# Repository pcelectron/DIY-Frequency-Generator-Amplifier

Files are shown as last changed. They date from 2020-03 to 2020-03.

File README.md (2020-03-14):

# DIY-Frequency-Generator-Amplifier

This is a open source frequency generator amplifier capable of delivering up to 1.5 Amps and 28 Vpp at up to 100MHz. It is based on three THS3491 IC's in parallel. The gain of the amplifier stage is fixed at 2, but can be changed by changing the feedback network resistors.
This Repo has the Kicad project files, gerbers, BOM and 3d models of the board and case. Please make a pull request if you have imporvements, which you find to be useful for others.

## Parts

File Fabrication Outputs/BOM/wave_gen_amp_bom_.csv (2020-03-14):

Component | References | Value | Footprint | Quantity Per PCB | digikey order number
1 | C7 C8 C9 C10 C11 C12 C28 | 100n | C_0603_1608Metric | 7 | C0603C104M5RACTU
2 | C13 C14 C15 C16 C17 C18 | 100p | C_0402_1005Metric | 6 | CC0402JRNPO9BN101
3 | C19 | 10n | C_0402_1005Metric | 1 | 311-1349-1-ND
4 | C1 C2 C3 C4 C5 C6 C20 C21 C22 C23 C24 C25 C26 C27 | 10u | C_1210_3225Metric | 14 | 1276-3387-1-ND
5 | D1 | D | S1M-13-F | 1 | S1M-13-F
6 | J1 | Banana Blue | banana_female_panel_mount | 1 | 108-0910-001
7 | J2 | Banana Black | banana_female_panel_mount | 1 | 108-0903-001
8 | J3 | Banana Red | banana_female_panel_mount | 1 | 108-0902-001
9 | J4 J5 | Conn_Coaxial | VBITE_BNC | 2 | 031-6233
10 | J7 | FAN | Conn_2x1_smd_horizontal | 1 | TSM-102-01-T-SH
11 | Q1 | DMG2302U | SOT-23 | 1 | DMG2302UK-7
12 | R11 | 12.4k | R_0603_1608Metric | 1 | RNCP0603FTD12K4CT-ND
13 | R10 | 140k | R_0603_1608Metric | 1 | RMCF0603FT140KCT-ND
14 | R13 R14 R17 R19 | 1k | R_0603_1608Metric | 4 | 311-1.00KHRCT-ND
15 | R7 R8 R9 | 2.4R | R_2010_5025Metric | 3 | 35022R4FT
16 | R18 | 3.2k | R_0603_1608Metric | 1 | 2019-RN73H1JTTD3201F100CT-ND
17 | R15 R16 | 30k | R_0603_1608Metric | 2 | 311-30.0KHRCT-ND
18 | R12 | 50R | R_0603_1608Metric | 1 | 541-2655-1-ND
19 | R1 R2 R3 R4 R5 R6 | 976R | R_0402_1005Metric | 6 | RP73PF1E976RBTD
20 | RV2 | COMP_REF | Trimpot_3.8mmx3.6mm_TC33X-2-103E | 1 | TC33X-2-103E
21 | RV1 | TJ_REF | Trimpot_3.8mmx3.6mm_TC33X-2-103E | 1 | TC33X-2-103E
22 | SH1 | RF_Shield_One_Piece | SHIELD | 1
23 | U6 | CU_SKV606021 | CU_SKV606021 | 1 | SKV606021-CU
24 | U4 | L7815 | TO-263-3 | 1 | L7815CD2T-TR
25 | U8 | LM2940 | SOT-223 | 1 | LM2940IMP-12/NOPBCT-ND
26 | U5 | LT3015 | DFN-8-1EP_3x3mm_P0.65mm_EP1.55x2.4mm | 1 | LT3015EDD#PBF
27 | U7 | OPA1679RUM | QFN-16-1EP_3x3mm_P0.5mm_EP1.7x1.7mm | 1 | OPA1679IRUMR
28 | U1 U2 U3 | THS3491 | QFN-16-1EP_3x3mm_P0.5mm_EP1.7x1.7mm_ThermalVias | 3 | THS3491IRGTT

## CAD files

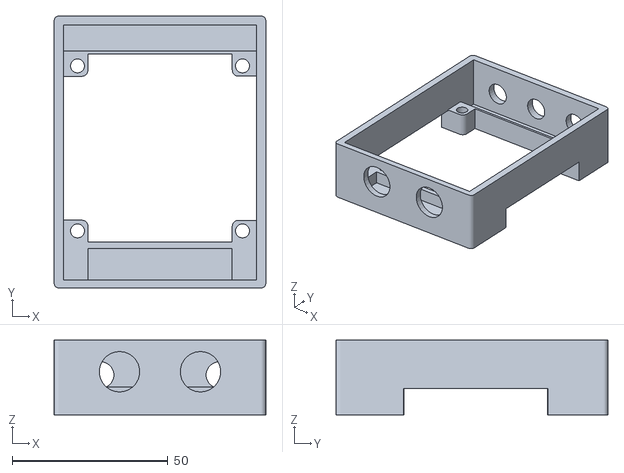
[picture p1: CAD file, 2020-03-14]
3D models/wave_gen_body.stl
68.0 x 87.4 x 24.0

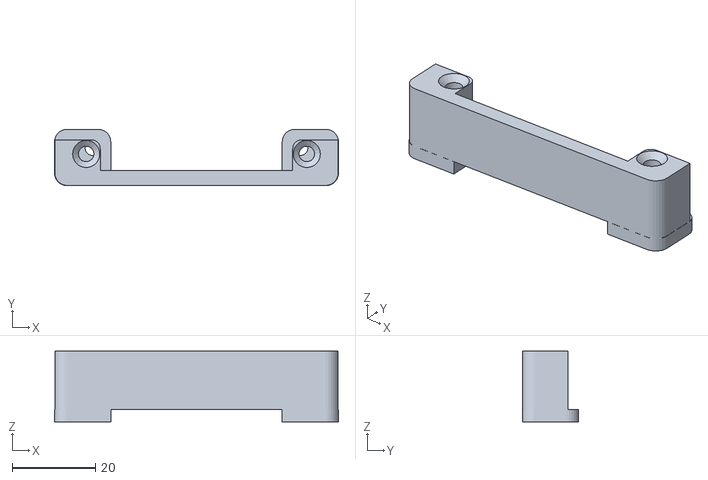
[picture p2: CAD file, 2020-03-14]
3D models/wave_gen_fan_holder.stl
68.1 x 13.5 x 17.0

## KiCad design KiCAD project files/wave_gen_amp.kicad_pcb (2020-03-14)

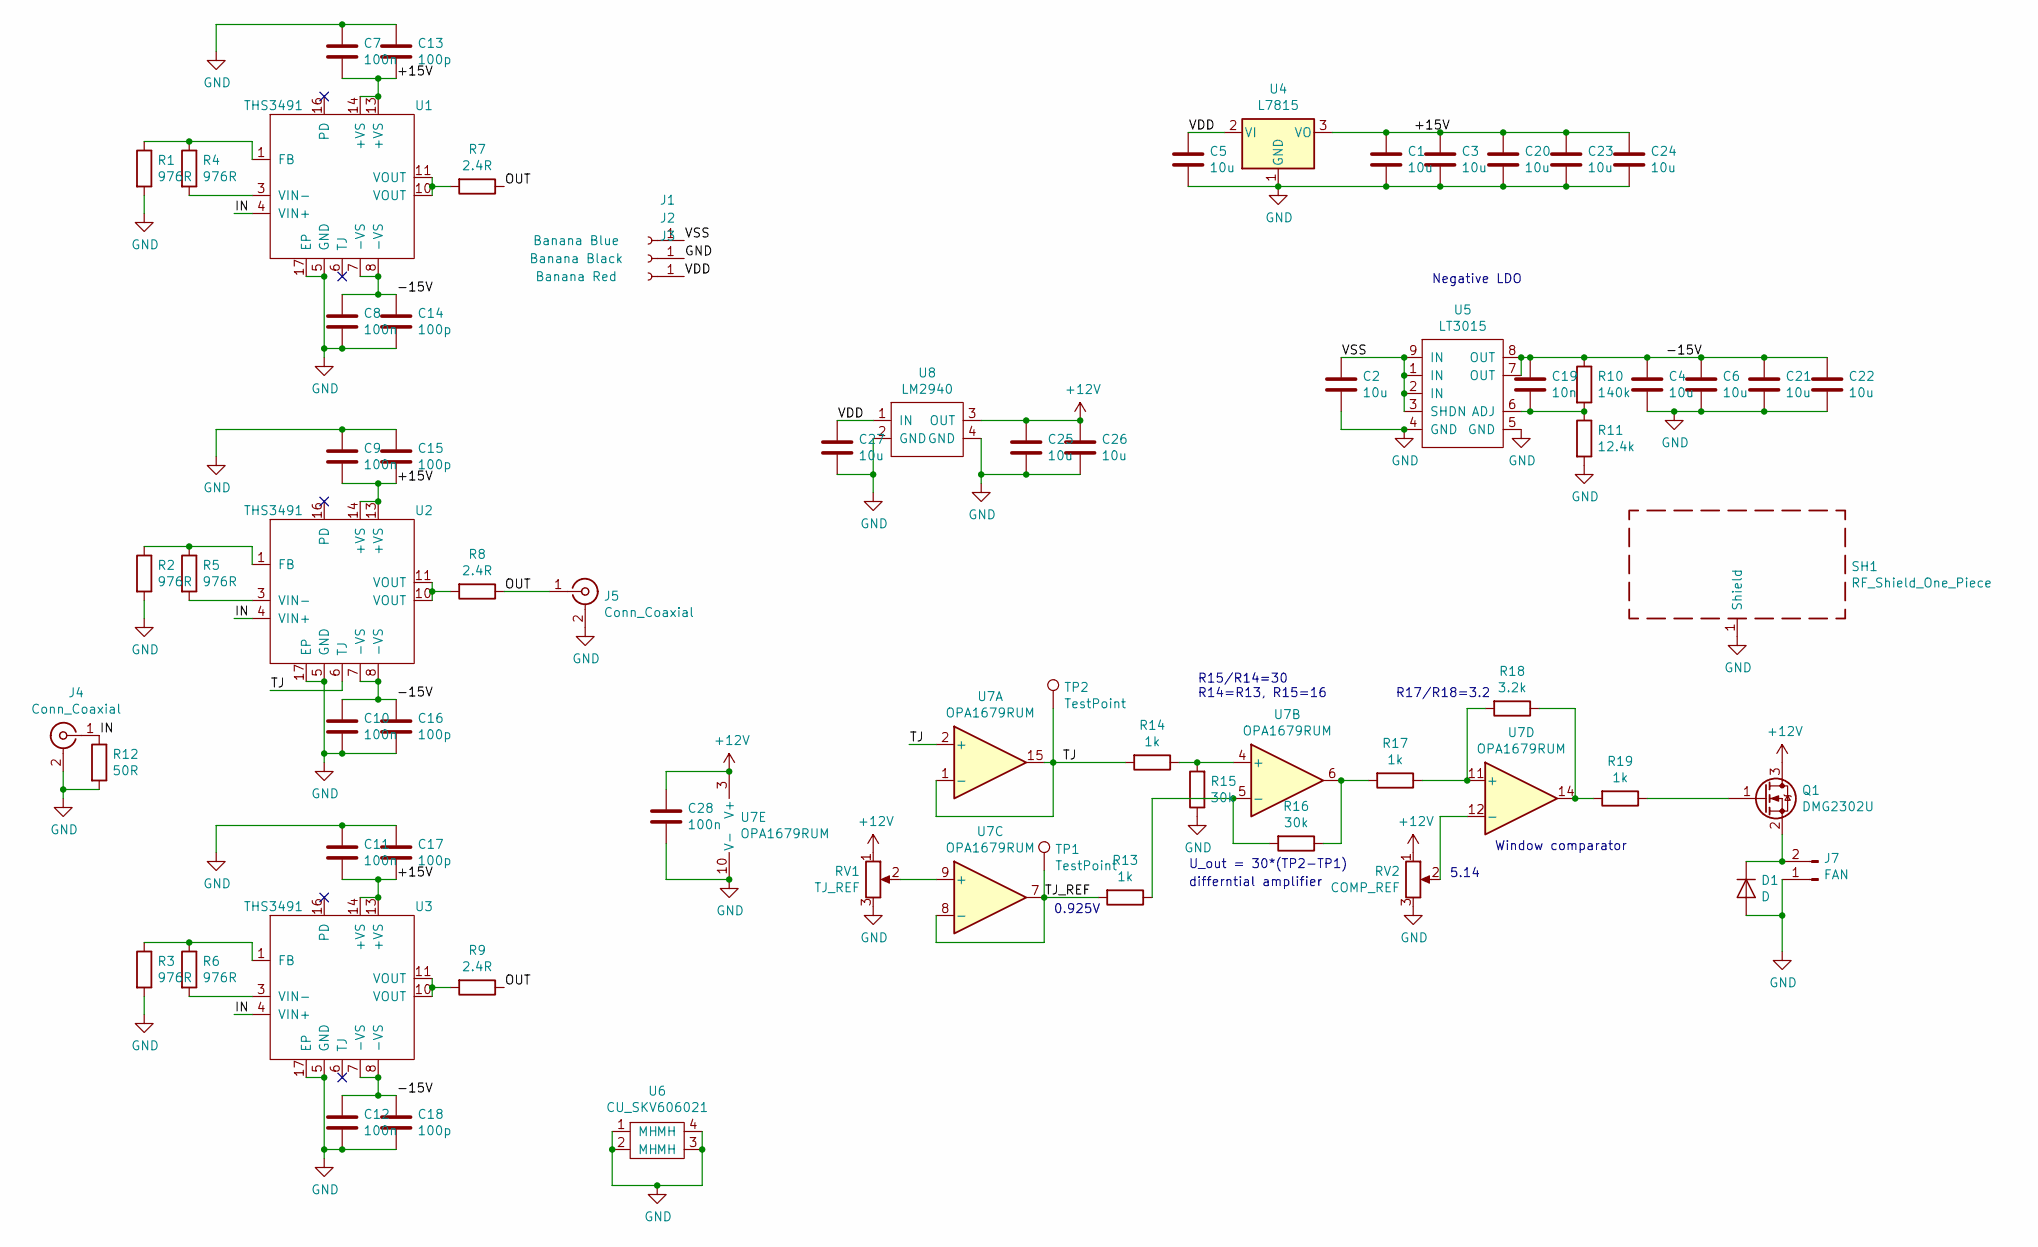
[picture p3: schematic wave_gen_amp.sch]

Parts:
C1, C2, C3, C4, C5, C6, C20, C21, C22, C23, C24, C25, C26, C27: 10u; C_1210_3225Metric; digikey order number 1276-3387-1-ND
C7, C8, C9, C10, C11, C12, C28: 100n; C_0603_1608Metric; digikey order number C0603C104M5RACTU
C13, C14, C15, C16, C17, C18: 100p; C_0402_1005Metric; digikey order number CC0402JRNPO9BN101
C19: 10n; C_0402_1005Metric; digikey order number 311-1349-1-ND
D1: D; S1M-13-F; digikey order number S1M-13-F
J1: Banana Blue; banana_female_panel_mount; digikey order number 108-0910-001
J2: Banana Black; banana_female_panel_mount; digikey order number 108-0903-001
J3: Banana Red; banana_female_panel_mount; digikey order number 108-0902-001
J4, J5: Conn_Coaxial; VBITE_BNC; digikey order number 031-6233
J7: FAN; Conn_2x1_smd_horizontal; digikey order number TSM-102-01-T-SH
Q1: DMG2302U; SOT-23; digikey order number DMG2302UK-7
R1, R2, R3, R4, R5, R6: 976R; R_0402_1005Metric; digikey order number RP73PF1E976RBTD
R7, R8, R9: 2.4R; R_2010_5025Metric; digikey order number 35022R4FT
R10: 140k; R_0603_1608Metric; digikey order number RMCF0603FT140KCT-ND
R11: 12.4k; R_0603_1608Metric; digikey order number RNCP0603FTD12K4CT-ND
R12: 50R; R_0603_1608Metric; digikey order number 541-2655-1-ND
R13, R14, R17, R19: 1k; R_0603_1608Metric; digikey order number 311-1.00KHRCT-ND
R15, R16: 30k; R_0603_1608Metric; digikey order number 311-30.0KHRCT-ND
R18: 3.2k; R_0603_1608Metric; digikey order number 2019-RN73H1JTTD3201F100CT-ND
RV1: TJ_REF; Trimpot_3.8mmx3.6mm_TC33X-2-103E; digikey order number TC33X-2-103E
RV2: COMP_REF; Trimpot_3.8mmx3.6mm_TC33X-2-103E; digikey order number TC33X-2-103E
SH1: RF_Shield_One_Piece; SHIELD
TP1, TP2: TestPoint; Testpoint 3mm
U1, U2, U3: THS3491; QFN-16-1EP_3x3mm_P0.5mm_EP1.7x1.7mm_ThermalVias; digikey order number THS3491IRGTT
U4: L7815; TO-263-3; digikey order number L7815CD2T-TR
U5: LT3015; DFN-8-1EP_3x3mm_P0.65mm_EP1.55x2.4mm; digikey order number LT3015EDD#PBF
U6: CU_SKV606021; digikey order number SKV606021-CU
U7: OPA1679RUM; QFN-16-1EP_3x3mm_P0.5mm_EP1.7x1.7mm; digikey order number OPA1679IRUMR
U8: LM2940; SOT-223; digikey order number LM2940IMP-12/NOPBCT-ND

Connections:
+12V: C25.1, C26.1, C28.1, Q1.3 (D), RV1.1, RV2.1, U7.3 (V+), U8.3 (OUT)
/+15V: C1.1, C3.1, C7.2, C9.2, C11.2, C13.2, C15.2, C17.2, C20.1, C23.1, C24.1, U1.13 (+VS), U1.14 (+VS), U2.13 (+VS), U2.14 (+VS), U3.13 (+VS), U3.14 (+VS), U4.3 (VO)
/-15V: C4.1, C6.1, C8.1, C10.1, C12.1, C14.1, C16.1, C18.1, C19.1, C21.1, C22.1, R10.1, U1.7 (-VS), U1.8 (-VS), U2.7 (-VS), U2.8 (-VS), U3.7 (-VS), U3.8 (-VS), U5.7 (OUT), U5.8 (OUT)
/IN: J4.1 (In), R12.1, U1.4 (VIN+), U2.4 (VIN+), U3.4 (VIN+)
/OUT: J5.1 (In), R7.1, R8.1, R9.1
/TJ: R14.2, TP2.1, U2.6 (TJ), U7.1 (-), U7.2 (+), U7.15
/TJ_REF: R13.2, TP1.1, U7.7, U7.8 (-)
/VDD: C5.1, C27.1, J3.1, U4.2 (VI), U8.1 (IN)
/VSS: C2.1, J1.1, U5.1 (IN), U5.2 (IN), U5.3 (SHDN), U5.9 (IN)
GND: C1.2, C2.2, C3.2, C4.2, C5.2, C6.2, C7.1, C8.2, C9.1, C10.2, C11.1, C12.2, C13.1, C14.2, C15.1, C16.2, C17.1, C18.2, C20.2, C21.2, C22.2, C23.2, C24.2, C25.2, C26.2, C27.2, C28.2, D1.2 (A), J2.1, J4.2 (Ext), J5.2 (Ext), J7.1, R1.2, R2.2, R3.2, R11.2, R12.2, R15.1, RV1.3, RV2.3, SH1.1, U1.5 (GND), U1.17 (EP), U2.5 (GND), U2.17 (EP), U3.5 (GND), U3.17 (EP), U4.1 (GND), U5.4 (GND), U5.5 (GND), U6.1, U6.2, U6.3, U6.4, U7.10 (V-), U7.17, U8.2 (GND), U8.4 (GND)
unnamed: C19.2, R10.2, R11.1, U5.6 (ADJ)
unnamed: D1.1 (K), J7.2, Q1.2 (S)
unnamed: Q1.1 (G), R19.1
unnamed: R1.1, R4.1, U1.1 (FB)
unnamed: R2.1, R5.1, U2.1 (FB)
unnamed: R3.1, R6.1, U3.1 (FB)
unnamed: R4.2, U1.3 (VIN-)
unnamed: R5.2, U2.3 (VIN-)
unnamed: R6.2, U3.3 (VIN-)
unnamed: R7.2, U1.10 (VOUT), U1.11 (VOUT)
unnamed: R8.2, U2.10 (VOUT), U2.11 (VOUT)
unnamed: R9.2, U3.10 (VOUT), U3.11 (VOUT)
unnamed: R13.1, R16.2, U7.5 (-)
unnamed: R14.1, R15.2, U7.4 (+)
unnamed: R16.1, R17.2, U7.6
unnamed: R17.1, R18.2, U7.11 (+)
unnamed: R18.1, R19.2, U7.14
unnamed: RV1.2, U7.9 (+)
unnamed: RV2.2, U7.12 (-)

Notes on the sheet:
Negative LDO
0.925V
5.14
R17/R18=3.2
R15/R14=30 R14=R13, R15=16
U_out = 30*(TP2-TP1)
Window comparator
differntial amplifier

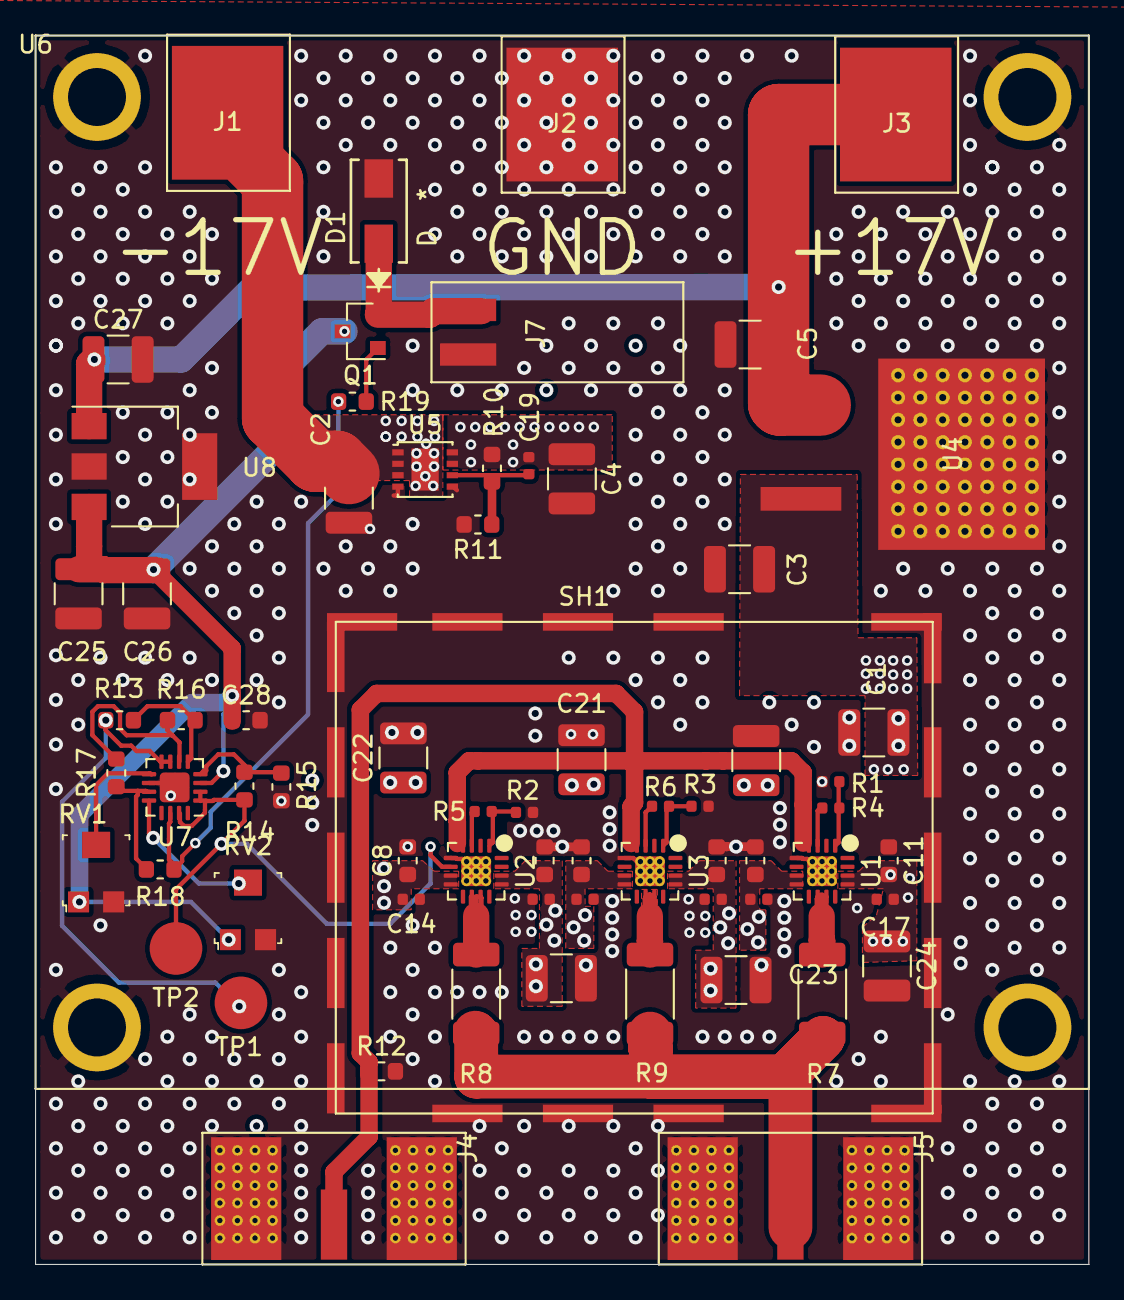
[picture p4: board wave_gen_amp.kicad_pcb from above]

Board: 2 copper layers, 60.0 x 70.0 mm, 68 parts (0 on the bottom side), 29 nets.

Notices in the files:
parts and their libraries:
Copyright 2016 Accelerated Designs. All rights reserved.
